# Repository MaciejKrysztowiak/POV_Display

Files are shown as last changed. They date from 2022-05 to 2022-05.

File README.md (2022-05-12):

# PERSISTANCE OF VISION DISPLAY

## PRINCIPLE

The working principle of persistance of vision display is that human eye cannot process more than 12 images per second. So by turning on and off moving LEDs it is possible to create an illusion of a stationary image.

## ELECTRONICS

As the main purpose of this display is to have a fancy wall clock, one of the main concerns in electronics design was power usage. That's why I decided to use STM32L051C8 as the main MCU, due to its low power usage, high computational capabilities and my familiarity with STM's HAL interface. For driving LEDs I choose a combination of classical 74HC595 8-bit SIPO registers and current limiting resistors. For a position sensor I used a low power Hall sensor **which I had problems with, described below**.

Using the KiCad software I came up with following schematic:
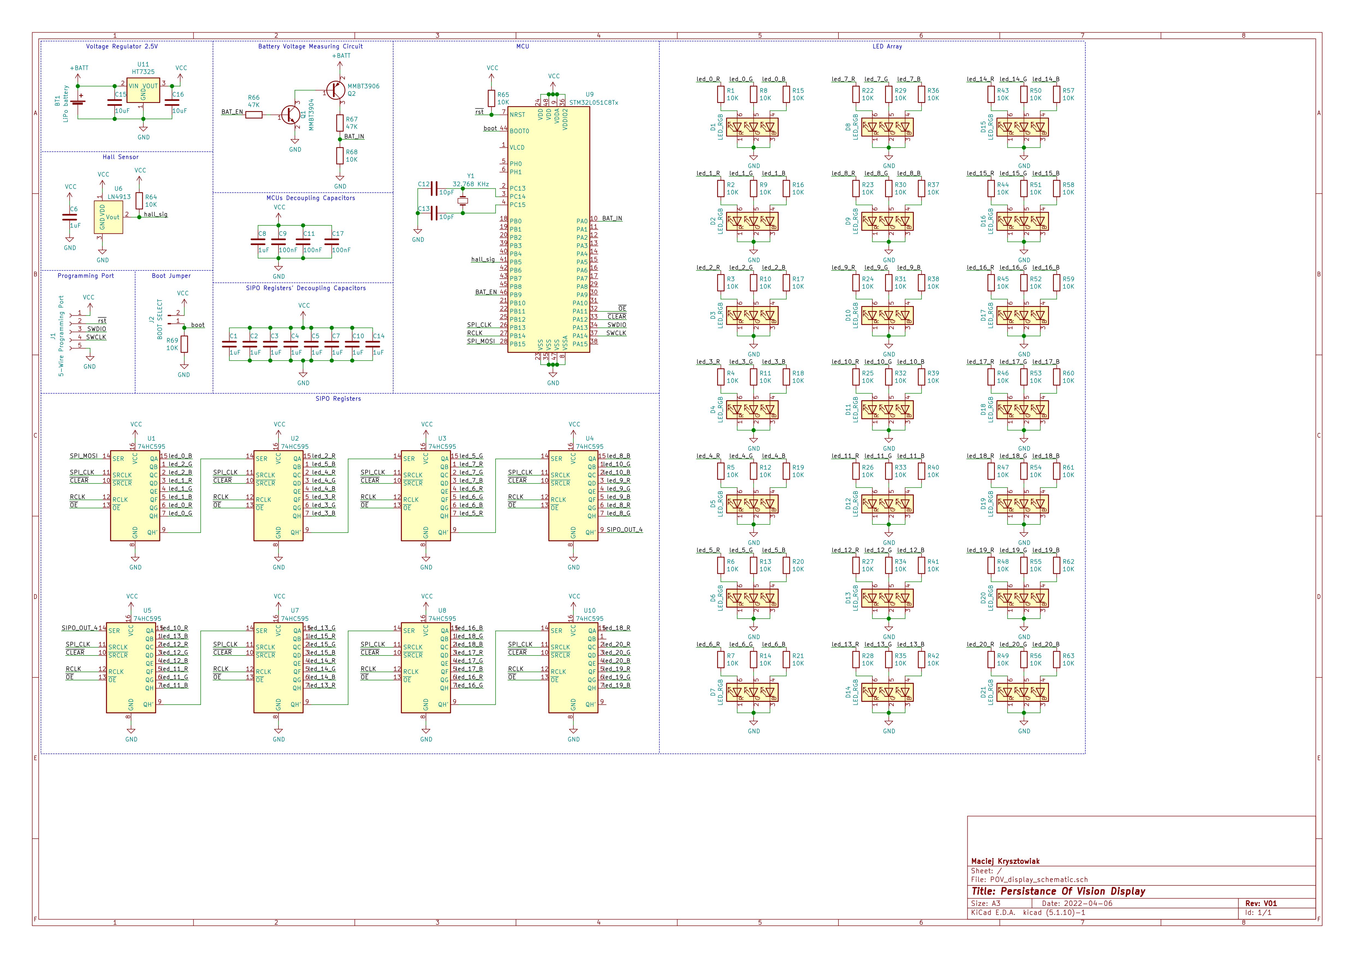
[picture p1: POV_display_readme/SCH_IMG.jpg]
Schematic


And PCB design:
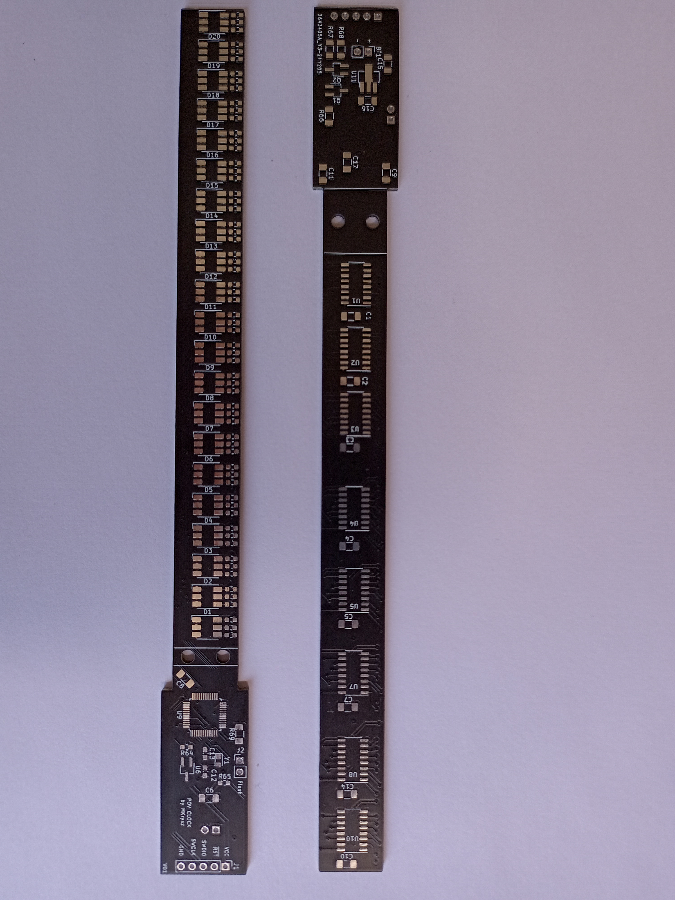
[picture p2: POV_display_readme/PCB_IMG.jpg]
PCB


After everything was soldered in, I began writing software and I couldn't get reliable data from used Hall sensor, so I was forced to change it to a combination of phototransistor with schmitt inverter trigger on propellers side and IR diode on motors side.

## MECHANICS

TODO:KAROL

## SOFTWARE

### IMAGE COMPILER

Python script used for compiling png images to a C-style array, that could be programmed into the MCU.

### FIRMWARE

Written in C using STMs CubeMx with HAL library in VSCode using Makefile toolchain. It's based around 2 independent timers, one responsible for measuring period of full rotation, the other responsible for ensuring proper timing in changing LEDs colors.

## END RESULT

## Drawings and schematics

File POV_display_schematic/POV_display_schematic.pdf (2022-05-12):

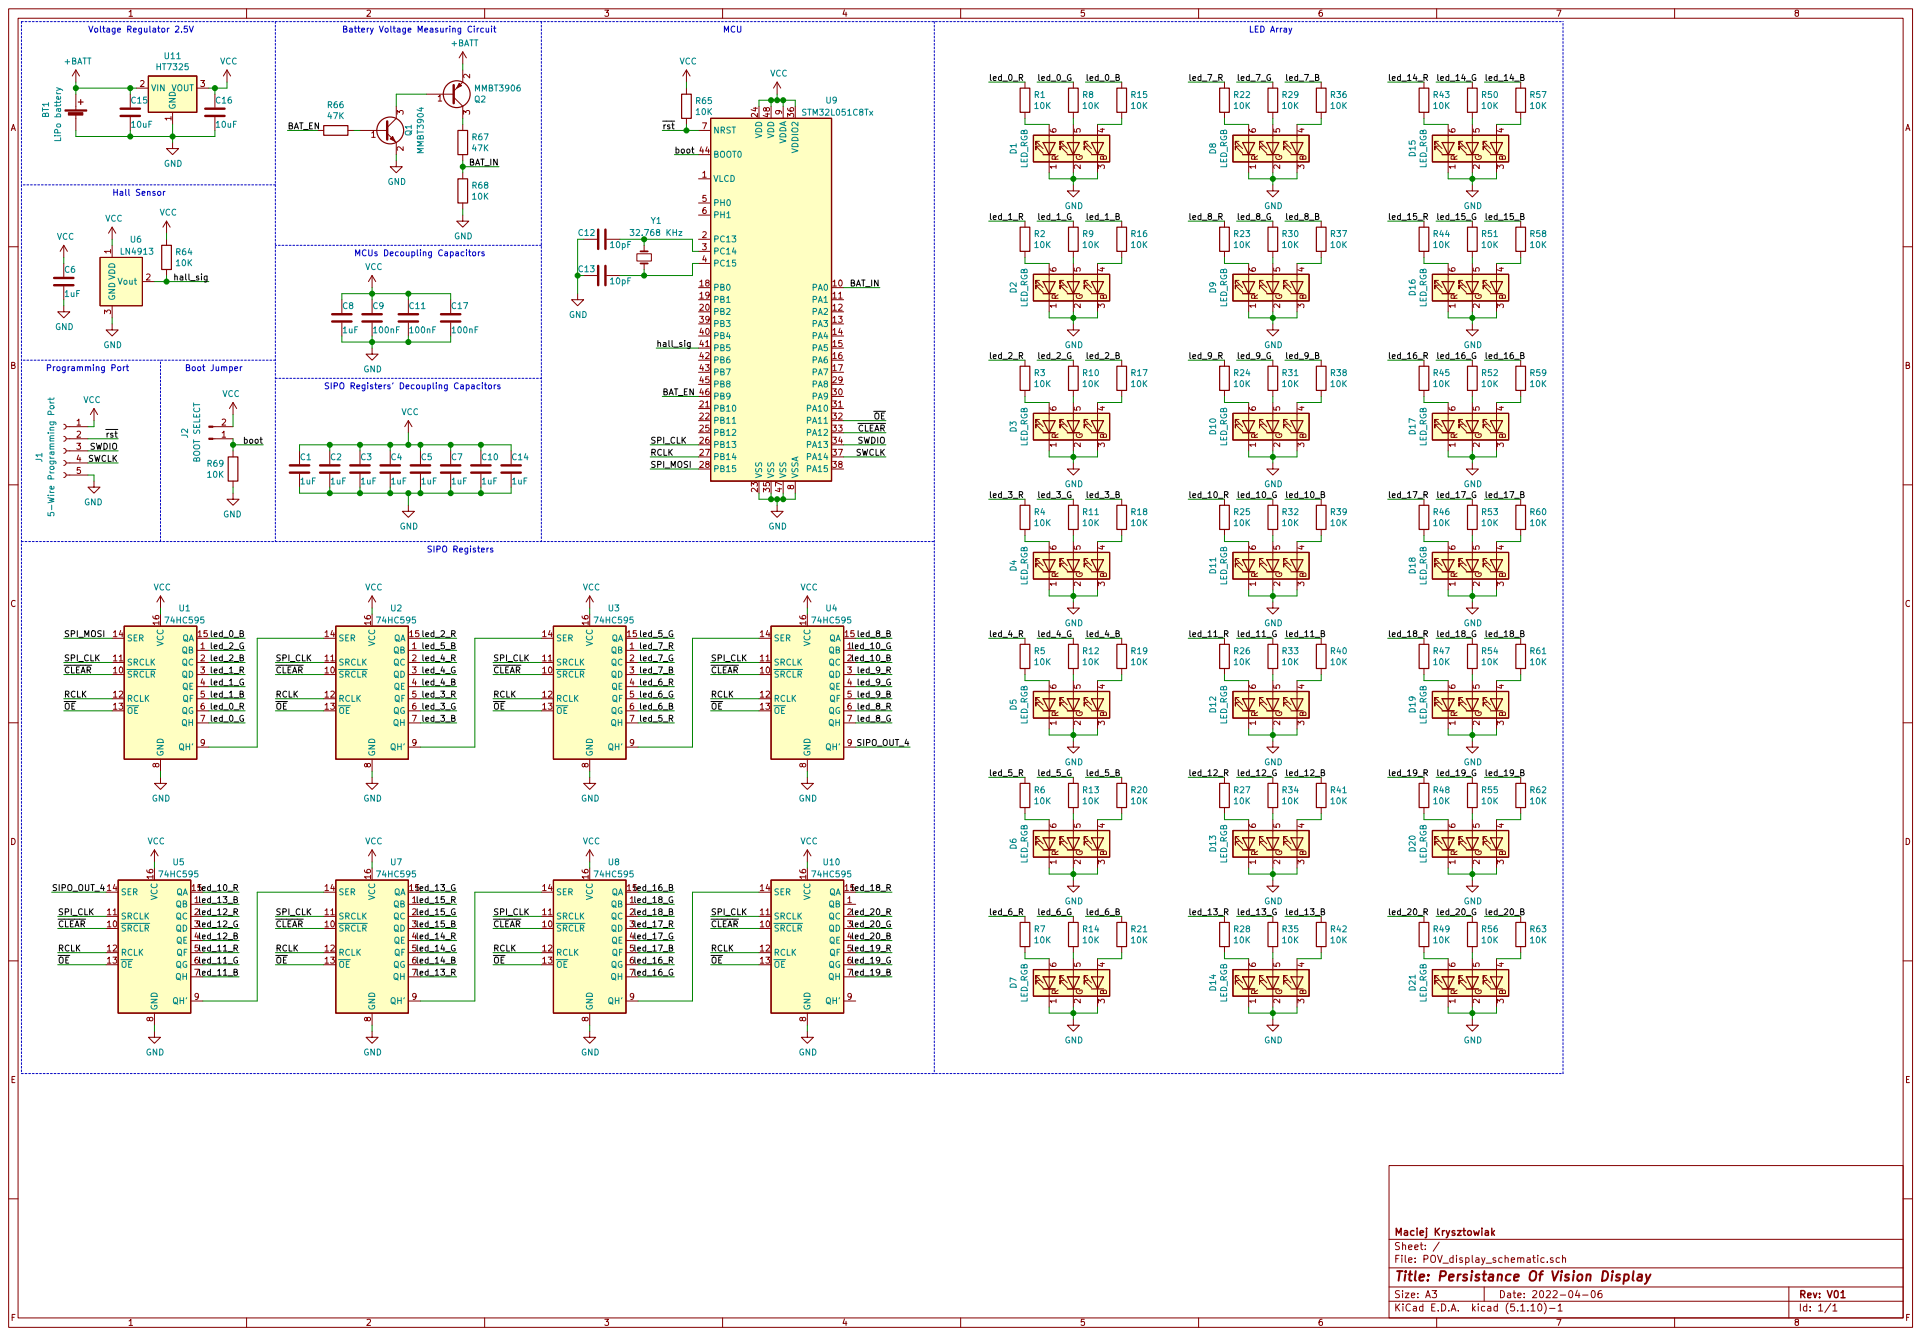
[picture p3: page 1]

4 D1 LED_RGB BT1 LiPo battery GND GND

9 VDDIO2 36 VLCD 1 VSS 23 VSS 35 VSS 47 VSSA

SIPO Registers' Decoupling Capacitors

led_12_R | led_15_G
led_12_G | led_15_B

led_11_R | led_14_G
led_11_G | led_14_B

File: POV_display_schematic.sch Sheet: / Maciej Krysztowiak

Id: 1/1 Title: Persistance Of Vision Display

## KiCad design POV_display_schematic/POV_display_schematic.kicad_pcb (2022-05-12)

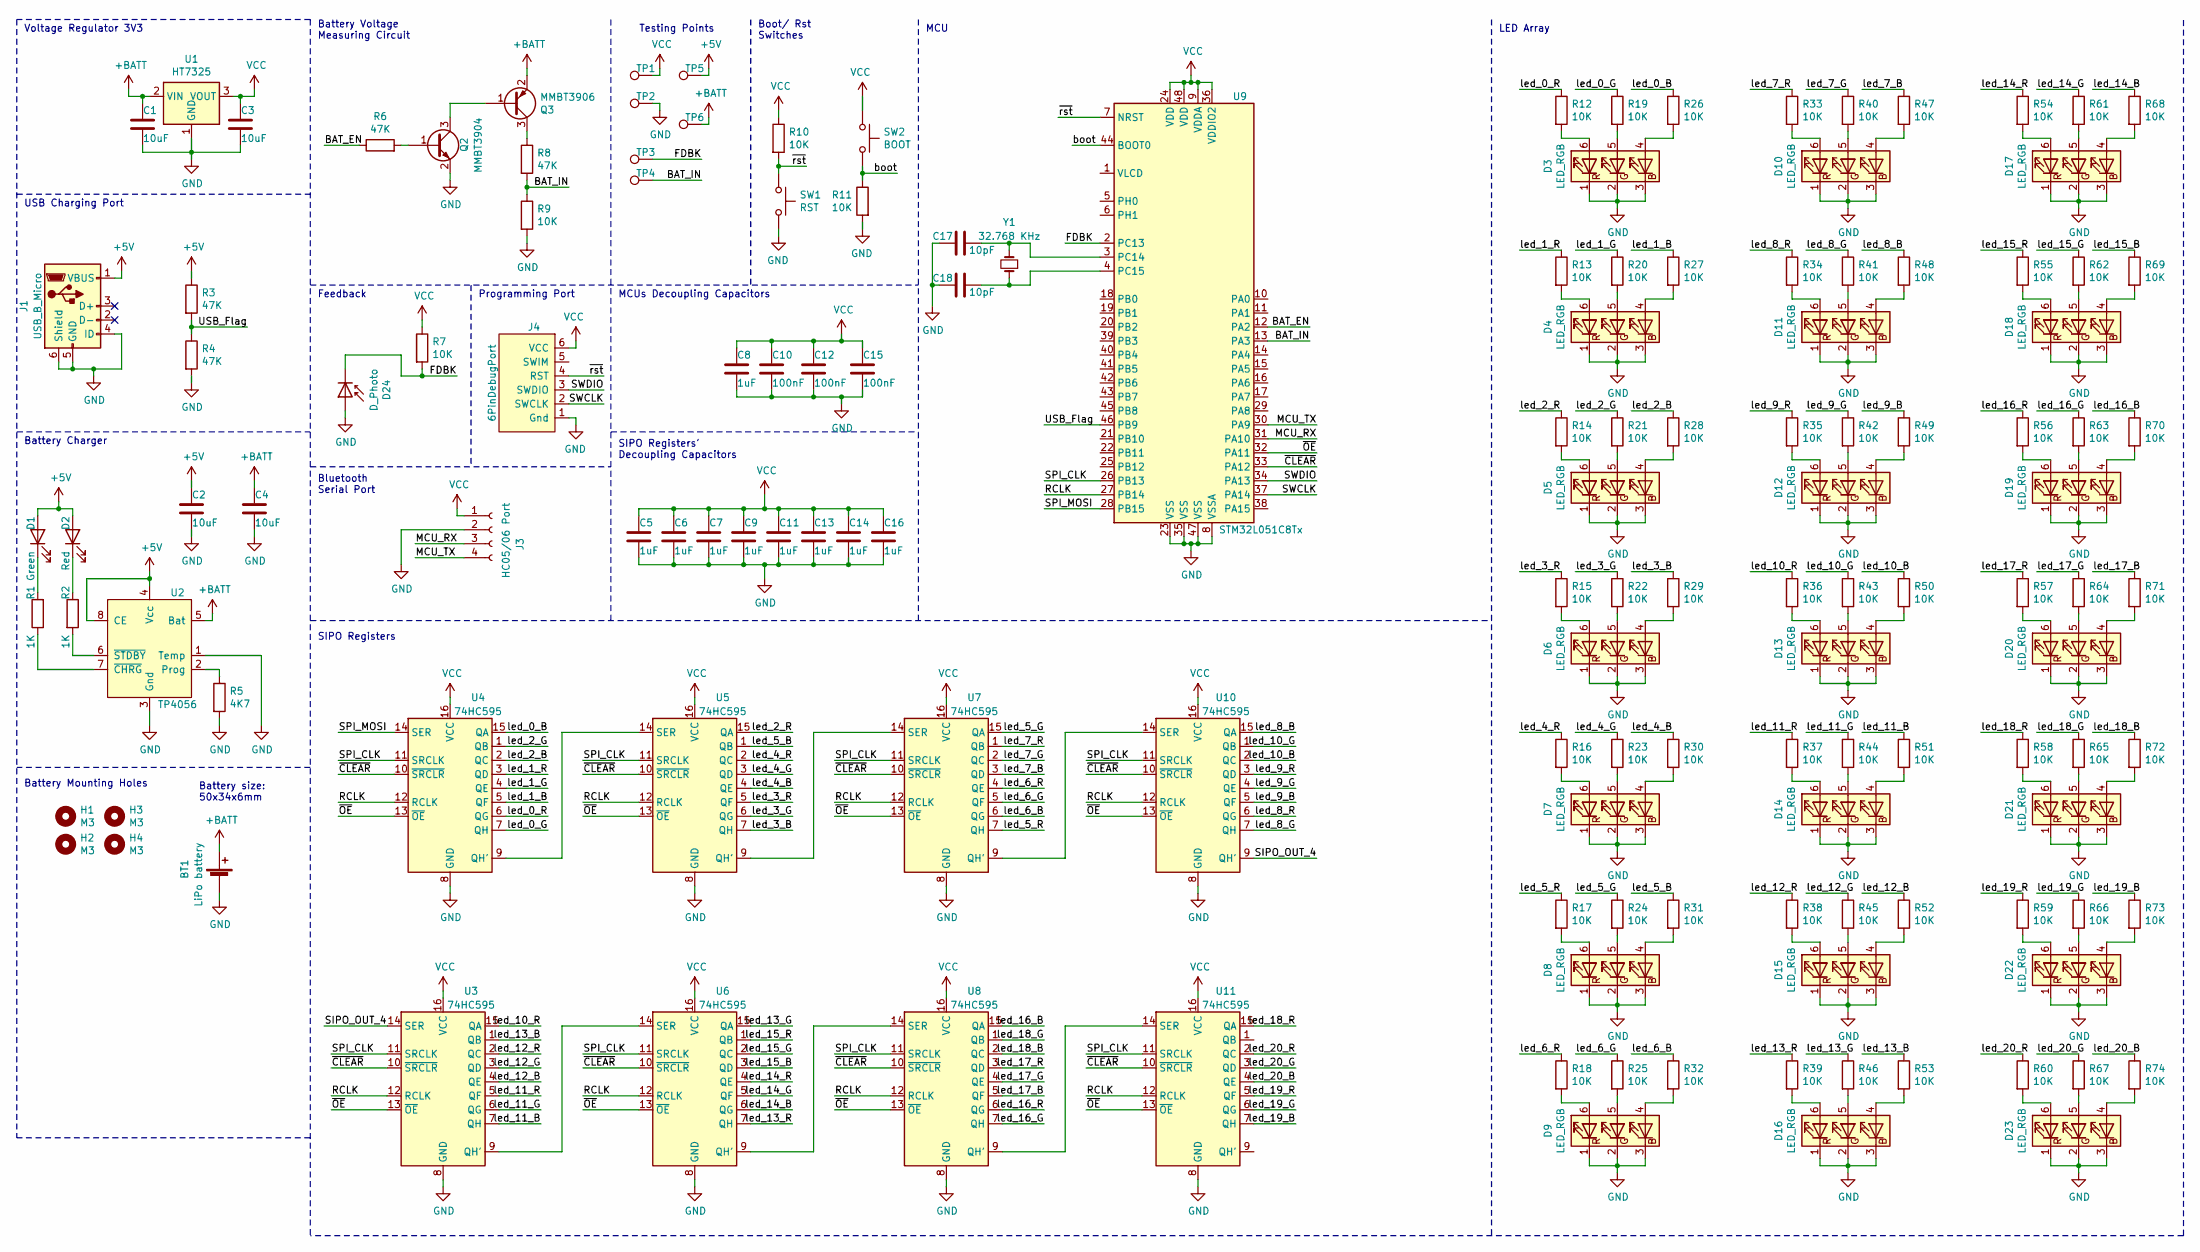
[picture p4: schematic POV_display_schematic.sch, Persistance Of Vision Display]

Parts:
BT1: LiPo battery; PinHeader_1x02_P2.54mm_Vertical
C1, C2, C3, C4: 10uF; C_0805_2012Metric_Pad1.18x1.45mm_HandSolder
C5, C6, C7, C8, C9, C11, C13, C14, C16: 1uF; C_0805_2012Metric_Pad1.18x1.45mm_HandSolder
C10, C12, C15: 100nF; C_0805_2012Metric_Pad1.18x1.45mm_HandSolder
C17, C18: 10pF; C_0603_1608Metric_Pad1.08x0.95mm_HandSolder
D1: Green; LED_0805_2012Metric_Pad1.15x1.40mm_HandSolder
D2: Red; LED_0805_2012Metric_Pad1.15x1.40mm_HandSolder
D3, D4, D5, D6, D7, D8, D9, D10, D11, D12, D13, D14, D15, D16, D17, D18, D19, D20, D21, D22, D23: LED_RGB; LED_RGB_5050-6
D24: D_Photo; LED_D5.0mm
H1, H2, H3, H4: M3; MountingHole_3.2mm_M3
J1: USB_B_Micro; USB_Micro-B_Molex-105017-0001
J3: HC05/06 Port; PinHeader_1x04_P2.54mm_Vertical
J4: 6PinDebugPort; IDC-Header_2x03_P2.54mm_Vertical
Q2: MMBT3904; TSOT-23_HandSoldering
Q3: MMBT3906; TSOT-23_HandSoldering
R1, R2: 1K; R_0805_2012Metric_Pad1.20x1.40mm_HandSolder
R3, R4, R6, R8: 47K; R_0805_2012Metric_Pad1.20x1.40mm_HandSolder
R5: 4K7; R_0805_2012Metric_Pad1.20x1.40mm_HandSolder
R7, R9, R10, R11: 10K; R_0805_2012Metric_Pad1.20x1.40mm_HandSolder
R12, R13, R14, R15, R16, R17, R18, R19, R20, R21, R22, R23, R24, R25, R26, R27, R28, R29, R30, R31, R32, R33, R34, R35, R36, R37, R38, R39, R40, R41, R42, R43, R44, R45, R46, R47, R48, R49, R50, R51, R52, R53, R54, R55, R56, R57, R58, R59, R60, R61, R62, R63, R64, R65, R66, R67, R68, R69, R70, R71, R72, R73, R74: 10K; R_0603_1608Metric
SW1: RST; TSB008
SW2: BOOT; TSB008
TP1, TP2, TP3, TP4, TP5, TP6: TestPoint; TestPoint_Pad_2.0x2.0mm
U1: HT7325; SOT-89-3_Handsoldering
U2: TP4056; SOP-8_3.9x4.9mm_P1.27mm
U3, U4, U5, U6, U7, U8, U10, U11: 74HC595; SO-16_3.9x9.9mm_P1.27mm
U9: STM32L051C8Tx; LQFP-48_7x7mm_P0.5mm
Y1: 32.768 KHz; Crystal_SMD_2012-2Pin_2.0x1.2mm_HandSoldering

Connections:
+5V: C2.1, D1.2 (A), D2.2 (A), J1.1 (VBUS), R3.1, TP5.1, U2.4 (Vcc), U2.8 (CE)
+BATT: BT1.1 (+), C1.1, C4.1, Q3.2 (E), TP6.1, U1.2 (VIN), U2.5 (Bat)
/BAT_EN: R6.1, U9.12 (PA2)
/BAT_IN: R8.2, R9.1, TP4.1, U9.13 (PA3)
/FDBK: D24.1 (K), R7.2, TP3.1, U9.2 (PC13)
/MCU_RX: J3.3, U9.31 (PA10)
/MCU_TX: J3.4, U9.30 (PA9)
/RCLK: U3.12 (RCLK), U4.12 (RCLK), U5.12 (RCLK), U6.12 (RCLK), U7.12 (RCLK), U8.12 (RCLK), U9.27 (PB14), U10.12 (RCLK), U11.12 (RCLK)
/SIPO_OUT_4: U3.14 (SER), U10.9 (QH')
/SPI_CLK: U3.11 (SRCLK), U4.11 (SRCLK), U5.11 (SRCLK), U6.11 (SRCLK), U7.11 (SRCLK), U8.11 (SRCLK), U9.26 (PB13), U10.11 (SRCLK), U11.11 (SRCLK)
/SPI_MOSI: U4.14 (SER), U9.28 (PB15)
/SWCLK: J4.2 (SWCLK), U9.37 (PA14)
/SWDIO: J4.3 (SWDIO), U9.34 (PA13)
/USB_Flag: R3.2, R4.1, U9.46 (PB9)
/boot: R11.1, SW2.2, U9.44 (BOOT0)
/led_0_B: R26.1, U4.15 (QA)
/led_0_G: R19.1, U4.7 (QH)
/led_0_R: R12.1, U4.6 (QG)
/led_1_B: R27.1, U4.5 (QF)
/led_1_G: R20.1, U4.4 (QE)
/led_1_R: R13.1, U4.3 (QD)
/led_2_B: R28.1, U4.2 (QC)
/led_2_G: R21.1, U4.1 (QB)
/led_2_R: R14.1, U5.15 (QA)
/led_3_B: R29.1, U5.7 (QH)
/led_3_G: R22.1, U5.6 (QG)
/led_3_R: R15.1, U5.5 (QF)
/led_4_B: R30.1, U5.4 (QE)
/led_4_G: R23.1, U5.3 (QD)
/led_4_R: R16.1, U5.2 (QC)
/led_5_B: R31.1, U5.1 (QB)
/led_5_G: R24.1, U7.15 (QA)
/led_5_R: R17.1, U7.7 (QH)
/led_6_B: R32.1, U7.6 (QG)
/led_6_G: R25.1, U7.5 (QF)
/led_6_R: R18.1, U7.4 (QE)
/led_7_B: R47.1, U7.3 (QD)
/led_7_G: R40.1, U7.2 (QC)
/led_7_R: R33.1, U7.1 (QB)
/led_8_B: R48.1, U10.15 (QA)
/led_8_G: R41.1, U10.7 (QH)
/led_8_R: R34.1, U10.6 (QG)
/led_9_B: R49.1, U10.5 (QF)
/led_9_G: R42.1, U10.4 (QE)
/led_9_R: R35.1, U10.3 (QD)
/led_10_B: R50.1, U10.2 (QC)
/led_10_G: R43.1, U10.1 (QB)
/led_10_R: R36.1, U3.15 (QA)
/led_11_B: R51.1, U3.7 (QH)
/led_11_G: R44.1, U3.6 (QG)
/led_11_R: R37.1, U3.5 (QF)
/led_12_B: R52.1, U3.4 (QE)
/led_12_G: R45.1, U3.3 (QD)
/led_12_R: R38.1, U3.2 (QC)
/led_13_B: R53.1, U3.1 (QB)
/led_13_G: R46.1, U6.15 (QA)
/led_13_R: R39.1, U6.7 (QH)
/led_14_B: R68.1, U6.6 (QG)
/led_14_G: R61.1, U6.5 (QF)
/led_14_R: R54.1, U6.4 (QE)
/led_15_B: R69.1, U6.3 (QD)
/led_15_G: R62.1, U6.2 (QC)
/led_15_R: R55.1, U6.1 (QB)
/led_16_B: R70.1, U8.15 (QA)
/led_16_G: R63.1, U8.7 (QH)
/led_16_R: R56.1, U8.6 (QG)
/led_17_B: R71.1, U8.5 (QF)
/led_17_G: R64.1, U8.4 (QE)
/led_17_R: R57.1, U8.3 (QD)
/led_18_B: R72.1, U8.2 (QC)
/led_18_G: R65.1, U8.1 (QB)
/led_18_R: R58.1, U11.15 (QA)
/led_19_B: R73.1, U11.7 (QH)
/led_19_G: R66.1, U11.6 (QG)
/led_19_R: R59.1, U11.5 (QF)
/led_20_B: R74.1, U11.4 (QE)
/led_20_G: R67.1, U11.3 (QD)
/led_20_R: R60.1, U11.2 (QC)
/~CLEAR: U3.10 (~SRCLR), U4.10 (~SRCLR), U5.10 (~SRCLR), U6.10 (~SRCLR), U7.10 (~SRCLR), U8.10 (~SRCLR), U9.33 (PA12), U10.10 (~SRCLR), U11.10 (~SRCLR)
/~OE: U3.13 (~OE), U4.13 (~OE), U5.13 (~OE), U6.13 (~OE), U7.13 (~OE), U8.13 (~OE), U9.32 (PA11), U10.13 (~OE), U11.13 (~OE)
/~rst: J4.4 (RST), R10.2, SW1.1, U9.7 (NRST)
GND: BT1.2 (-), C1.2, C2.2, C3.2, C4.2, C5.2, C6.2, C7.2, C8.2, C9.2, C10.2, C11.2, C12.2, C13.2, C14.2, C15.2, C16.2, C17.1, C18.1, D3.1 (RK), D3.2 (GK), D3.3 (BK), D4.1 (RK), D4.2 (GK), D4.3 (BK), D5.1 (RK), D5.2 (GK), D5.3 (BK), D6.1 (RK), D6.2 (GK), D6.3 (BK), D7.1 (RK), D7.2 (GK), D7.3 (BK), D8.1 (RK), D8.2 (GK), D8.3 (BK), D9.1 (RK), D9.2 (GK), D9.3 (BK), D10.1 (RK), D10.2 (GK), D10.3 (BK), D11.1 (RK), D11.2 (GK), D11.3 (BK), D12.1 (RK), D12.2 (GK), D12.3 (BK), D13.1 (RK), D13.2 (GK), D13.3 (BK), D14.1 (RK), D14.2 (GK), D14.3 (BK), D15.1 (RK), D15.2 (GK), D15.3 (BK), D16.1 (RK), D16.2 (GK), D16.3 (BK), D17.1 (RK), D17.2 (GK), D17.3 (BK), D18.1 (RK), D18.2 (GK), D18.3 (BK), D19.1 (RK), D19.2 (GK), D19.3 (BK), D20.1 (RK), D20.2 (GK), D20.3 (BK), D21.1 (RK), D21.2 (GK), D21.3 (BK), D22.1 (RK), D22.2 (GK), D22.3 (BK), D23.1 (RK), D23.2 (GK), D23.3 (BK), D24.2 (A), J1.4 (ID), J1.5 (GND), J1.6 (Shield), J3.2, J4.1 (Gnd), Q2.2 (E), R4.2, R5.2, R9.2, R11.2, SW1.2, TP2.1, U1.1 (GND), U2.1 (Temp), U2.3 (Gnd), U3.8 (GND), U4.8 (GND), U5.8 (GND), U6.8 (GND), U7.8 (GND), U8.8 (GND), U9.8 (VSSA), U9.23 (VSS), U9.35 (VSS), U9.47 (VSS), U10.8 (GND), U11.8 (GND)
unnamed: C17.2, U9.3 (PC14), Y1.2
unnamed: C18.2, U9.4 (PC15), Y1.1
unnamed: D1.1 (K), R1.2
unnamed: D2.1 (K), R2.1
unnamed: D3.4 (BA), R26.2
unnamed: D3.5 (GA), R19.2
unnamed: D3.6 (RA), R12.2
unnamed: D4.4 (BA), R27.2
unnamed: D4.5 (GA), R20.2
unnamed: D4.6 (RA), R13.2
unnamed: D5.4 (BA), R28.2
unnamed: D5.5 (GA), R21.2
unnamed: D5.6 (RA), R14.2
unnamed: D6.4 (BA), R29.2
unnamed: D6.5 (GA), R22.2
unnamed: D6.6 (RA), R15.2
unnamed: D7.4 (BA), R30.2
unnamed: D7.5 (GA), R23.2
unnamed: D7.6 (RA), R16.2
unnamed: D8.4 (BA), R31.2
unnamed: D8.5 (GA), R24.2
unnamed: D8.6 (RA), R17.2
unnamed: D9.4 (BA), R32.2
unnamed: D9.5 (GA), R25.2
unnamed: D9.6 (RA), R18.2
unnamed: D10.4 (BA), R47.2
unnamed: D10.5 (GA), R40.2
unnamed: D10.6 (RA), R33.2
unnamed: D11.4 (BA), R48.2
unnamed: D11.5 (GA), R41.2
unnamed: D11.6 (RA), R34.2
unnamed: D12.4 (BA), R49.2
unnamed: D12.5 (GA), R42.2
unnamed: D12.6 (RA), R35.2
unnamed: D13.4 (BA), R50.2
unnamed: D13.5 (GA), R43.2
unnamed: D13.6 (RA), R36.2
unnamed: D14.4 (BA), R51.2
unnamed: D14.5 (GA), R44.2
unnamed: D14.6 (RA), R37.2
unnamed: D15.4 (BA), R52.2
unnamed: D15.5 (GA), R45.2
unnamed: D15.6 (RA), R38.2
unnamed: D16.4 (BA), R53.2
unnamed: D16.5 (GA), R46.2
unnamed: D16.6 (RA), R39.2
unnamed: D17.4 (BA), R68.2
unnamed: D17.5 (GA), R61.2
unnamed: D17.6 (RA), R54.2
unnamed: D18.4 (BA), R69.2
unnamed: D18.5 (GA), R62.2
unnamed: D18.6 (RA), R55.2
unnamed: D19.4 (BA), R70.2
unnamed: D19.5 (GA), R63.2
unnamed: D19.6 (RA), R56.2
unnamed: D20.4 (BA), R71.2
unnamed: D20.5 (GA), R64.2
unnamed: D20.6 (RA), R57.2
unnamed: D21.4 (BA), R72.2
unnamed: D21.5 (GA), R65.2
unnamed: D21.6 (RA), R58.2
unnamed: D22.4 (BA), R73.2
unnamed: D22.5 (GA), R66.2
unnamed: D22.6 (RA), R59.2
unnamed: D23.4 (BA), R74.2
unnamed: D23.5 (GA), R67.2
unnamed: D23.6 (RA), R60.2
unnamed: Q2.1 (B), R6.2
unnamed: Q2.3 (C), Q3.1 (B)
unnamed: Q3.3 (C), R8.1
unnamed: R1.1, U2.7 (~CHRG)
unnamed: R2.2, U2.6 (~STDBY)
unnamed: R5.1, U2.2 (Prog)
unnamed: U3.9 (QH'), U6.14 (SER)
unnamed: U4.9 (QH'), U5.14 (SER)
unnamed: U5.9 (QH'), U7.14 (SER)
unnamed: U6.9 (QH'), U8.14 (SER)
unnamed: U7.9 (QH'), U10.14 (SER)
unnamed: U8.9 (QH'), U11.14 (SER)
VCC: C3.1, C5.1, C6.1, C7.1, C8.1, C9.1, C10.1, C11.1, C12.1, C13.1, C14.1, C15.1, C16.1, J3.1, J4.6 (VCC), R7.1, R10.1, SW2.1, TP1.1, U1.3 (VOUT), U3.16 (VCC), U4.16 (VCC), U5.16 (VCC), U6.16 (VCC), U7.16 (VCC), U8.16 (VCC), U9.9 (VDDA), U9.24 (VDD), U9.36 (VDDIO2), U9.48 (VDD), U10.16 (VCC), U11.16 (VCC)

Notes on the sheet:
Voltage Regulator 3V3
Battery Voltage Measuring Circuit
MCU
MCUs Decoupling Capacitors
Feedback
Programming Port
Boot/ Rst Switches
LED Array
USB Charging Port
SIPO Registers' Decoupling Capacitors
SIPO Registers
Battery Charger
Battery Mounting Holes
Testing Points
Bluetooth Serial Port
Battery size: 50x34x6mm

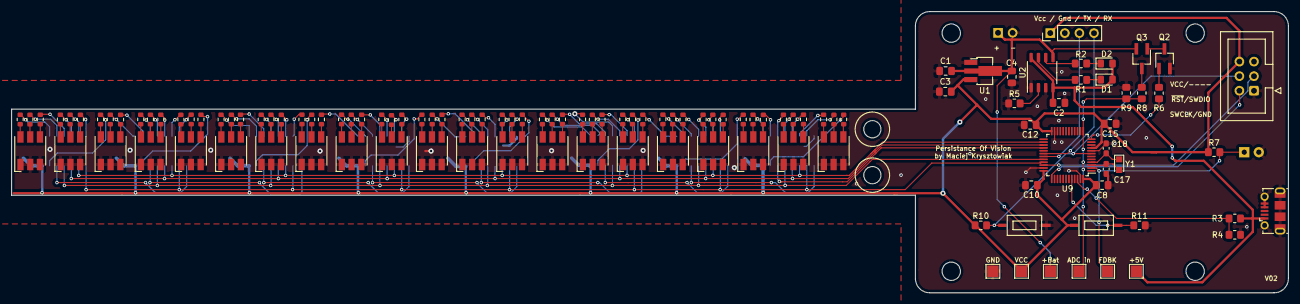
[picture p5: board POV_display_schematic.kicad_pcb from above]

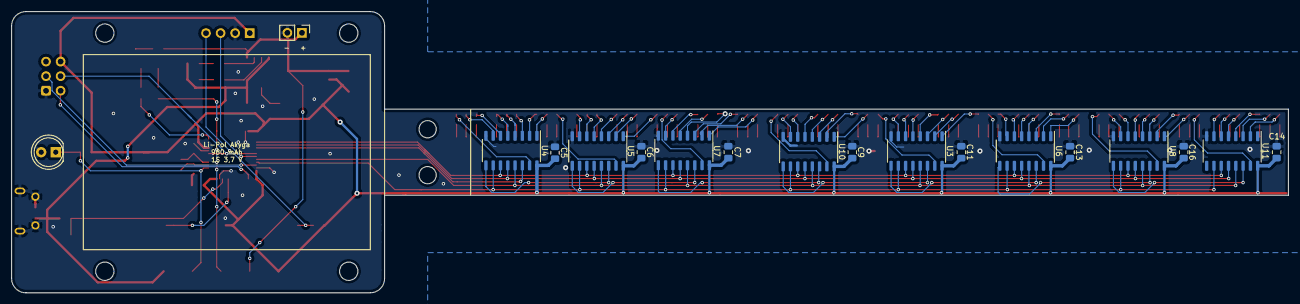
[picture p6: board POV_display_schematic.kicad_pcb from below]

Board: 2 copper layers, 222.5 x 49.0 mm, 146 parts (18 on the bottom side), 162 nets.

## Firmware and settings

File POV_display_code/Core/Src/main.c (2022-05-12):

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
/* Includes ------------------------------------------------------------------*/
#include "main.h"
#include "adc.h"
#include "dma.h"
#include "rtc.h"
#include "spi.h"
#include "tim.h"
#include "gpio.h"

/* USER CODE BEGIN Includes */
#include "led.h"
#include "clk.h"
#include "array.h"
#include <stdbool.h>
/* USER CODE END Includes */

/* USER CODE BEGIN PD */
// #define MODE_IMAGE
#define MODE_ANALOG_CLOCK
// #define MODE_DIGITAL_CLOCK
/* USER CODE END PD */


/* USER CODE BEGIN PV */
/**
 * @brief time of full rotation in ms
 * 
 */
volatile uint16_t period = 0;

/**
 * @brief time of full rotation in us
 * 
 */
volatile uint16_t periodUS = 0;


volatile size_t imgIdx = 0;

#include "img.h"

/* USER CODE END PV */

void SystemClock_Config(void);
/* USER CODE BEGIN PFP */
void sleepRoutine();
/* USER CODE END PFP */

/**
  * @brief  The application entry point.
  * @retval int
  */
int main(void)
{
  /* MCU Configuration--------------------------------------------------------*/

  /* Reset of all peripherals, Initializes the Flash interface and the Systick. */
  HAL_Init();

  /* Configure the system clock */
  SystemClock_Config();

  /* Initialize all configured peripherals */
  MX_GPIO_Init();
  MX_ADC_Init();
  MX_SPI2_Init();
  MX_RTC_Init();
  MX_DMA_Init();
  MX_TIM6_Init();
  MX_TIM21_Init();
  MX_TIM22_Init();
  MX_TIM2_Init();
  /* USER CODE BEGIN 2 */
  TIM_Init();
  GPIO_Init();
  LED_Init();
  LED_AllBlack();
  HAL_Delay(1500);
  LED_AllWhite();
  HAL_Delay(1500);
  LED_AllBlack();
  HAL_Delay(2000);
  /* USER CODE END 2 */

  /* Infinite loop */
  /* USER CODE BEGIN WHILE */

  /**
   * @brief time in ms since last full rotation after which display goes dormant
   * 
   */
  const uint16_t shutdownTime = 500;

  while (1)
  {

    while(1)
    {


      #ifdef MODE_IMAGE

      const size_t imgIdxMax = IMG_SIZE;
      LED_Send(image[imgIdxMax-imgIdx-1]);

      #endif


      #ifdef MODE_ANALOG_CLOCK

      const size_t imgIdxMax = 120;
      uint8_t sendData[8];
      size_t tempIdx = imgIdx;         
      // size_t tempIdx = (imgIdx + imgIdxMax/2) % imgIdxMax;

      //add background
      ARRAY_Copy(CLK_BKGD[tempIdx], sendData, 8);

      // //add hands
      // RTC_TimeTypeDef currentTime; 
      // // HAL_RTC_GetTime(&hrtc, &currentTime, RTC_FORMAT_BIN);
      // currentTime.Hours = 3;
      // currentTime.Minutes = 30;
      // currentTime.Seconds = 45;

      // if(currentTime.Hours * 10 == tempIdx)
      //   ARRAY_BitwiseOR(sendData, hours, sendData, 8);
      // if(currentTime.Minutes * 2 == tempIdx)
      //   ARRAY_BitwiseOR(sendData, minutes, sendData, 8);
      // if(currentTime.Seconds * 2 == tempIdx)
      //   ARRAY_BitwiseOR(sendData, seconds, sendData, 8);

      LED_Send(sendData);

      #endif

      //progress in showing img
      imgIdx++;
      if(imgIdx == imgIdxMax){
        imgIdx = 0;
      }

      while(__HAL_TIM_GET_COUNTER(&HTIM_US_DELAY) < (uint16_t)(periodUS/imgIdxMax));
    __HAL_TIM_SET_COUNTER(&HTIM_US_DELAY, 0);

      // //calculate and execute delay
      // uint32_t delayDurationUS = (period * 1000) / imgIdxMax;
      // if(delayDurationUS > 60000){
      // //   while(__HAL_TIM_GET_COUNTER(&HTIM_MS_DELAY) < (uint16_t)(period/imgIdxMax));
      // // __HAL_TIM_SET_COUNTER(&HTIM_MS_DELAY, 0);
      // }
      // else{
      //   if(period > 60){
      //   //   while(__HAL_TIM_GET_COUNTER(&HTIM_US_DELAY) < (uint16_t)(delayDurationUS));
      //   // __HAL_TIM_SET_COUNTER(&HTIM_US_DELAY, 0);
      //   }
      //   else{
      //     while(__HAL_TIM_GET_COUNTER(&HTIM_US_DELAY) < (uint16_t)(periodUS/imgIdxMax));
      //   __HAL_TIM_SET_COUNTER(&HTIM_US_DELAY, 0);
      //   }
      // }


      //shutdown if no rotation detected for specified time
      if(__HAL_TIM_GET_COUNTER(&HTIM_MS_GET) >= shutdownTime){
        sleepRoutine();
      }

    }

    /* USER CODE END WHILE */

    /* USER CODE BEGIN 3 */
  }
  /* USER CODE END 3 */
}

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
/* USER CODE BEGIN 4 */
void sleepRoutine()
{
  LED_AllBlack();
  
  HAL_SuspendTick();
  HAL_PWR_EnterSTOPMode(PWR_LOWPOWERREGULATOR_ON, PWR_STOPENTRY_WFI);
}

/* USER CODE END 4 */
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


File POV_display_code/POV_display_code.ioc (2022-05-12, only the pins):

Mcu.UserName=STM32L051C8Tx
PA0.GPIO_Label=BAT_IN
PA0.Signal=ADC_IN0
PA10.Signal=USART1_RX
PA11.GPIO_Label=NOT_OE
PA11.Signal=GPIO_Output
PA12.GPIO_Label=NOT_CLEAR
PA12.Signal=GPIO_Output
PA13.Signal=SYS_SWDIO
PA14.Signal=SYS_SWCLK
PA2.GPIO_Label=IR_SIG
PA2.Signal=GPXTI2
PA3.GPIO_Label=DBG
PA3.Signal=GPIO_Output
PA9.Signal=USART1_TX
PB13.Signal=SPI2_SCK
PB14.GPIO_Label=RCLK
PB14.Signal=GPIO_Output
PB15.Signal=SPI2_MOSI
PB9.GPIO_Label=BAT_EN
PB9.Signal=GPIO_Output
PC14-OSC32_IN.Signal=RCC_OSC32_IN
PC15-OSC32_OUT.Signal=RCC_OSC32_OUT

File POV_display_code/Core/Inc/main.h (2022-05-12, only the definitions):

#define BAT_IN_Pin GPIO_PIN_0
#define BAT_IN_GPIO_Port GPIOA
#define IR_SIG_Pin GPIO_PIN_2
#define IR_SIG_GPIO_Port GPIOA
#define DBG_Pin GPIO_PIN_3
#define DBG_GPIO_Port GPIOA
#define RCLK_Pin GPIO_PIN_14
#define RCLK_GPIO_Port GPIOB
#define NOT_OE_Pin GPIO_PIN_11
#define NOT_OE_GPIO_Port GPIOA
#define NOT_CLEAR_Pin GPIO_PIN_12
#define NOT_CLEAR_GPIO_Port GPIOA
#define HAL_SIG_Pin GPIO_PIN_5
#define HAL_SIG_GPIO_Port GPIOB
#define HAL_SIG_EXTI_IRQn EXTI4_15_IRQn
#define BAT_EN_Pin GPIO_PIN_9
#define BAT_EN_GPIO_Port GPIOB

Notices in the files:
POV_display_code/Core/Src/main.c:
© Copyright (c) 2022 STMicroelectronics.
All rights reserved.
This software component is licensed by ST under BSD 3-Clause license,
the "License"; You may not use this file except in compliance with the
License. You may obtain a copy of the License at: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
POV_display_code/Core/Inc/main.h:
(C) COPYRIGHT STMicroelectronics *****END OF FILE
